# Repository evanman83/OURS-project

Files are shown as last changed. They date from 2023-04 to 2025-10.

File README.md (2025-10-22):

# OURS Project - DIY Open-Source Linux Smartphone

## MISSION:

I wanted to give people more options and control over their most personal device, so I created an **O**pen-source, **U**pgradable, **R**epairable **S**martphone, that is also completely free of Big Tech. It's not theirs, it's O.U.R.S. 

Below are the complete hardware and software instructions to build your own OURphone. Please enjoy, upgrade, tinker, improve and evolve my original design as you see fit, and share your upgrades here. Find me on [LinkedIn](https://www.linkedin.com/in/boyofthefuture/) if you have any questions / ideas.

**Version 1 was completed in 2024 - instructions are below. We are now busy with version 2**

**Join us on our [Telegram group](https://t.me/ourphonechat).**

**We are raising funds for version 2! Please support our campaign at [BuyMeACoffee](https://buymeacoffee.com/ourphone).**

## VERSION 1 PLANS

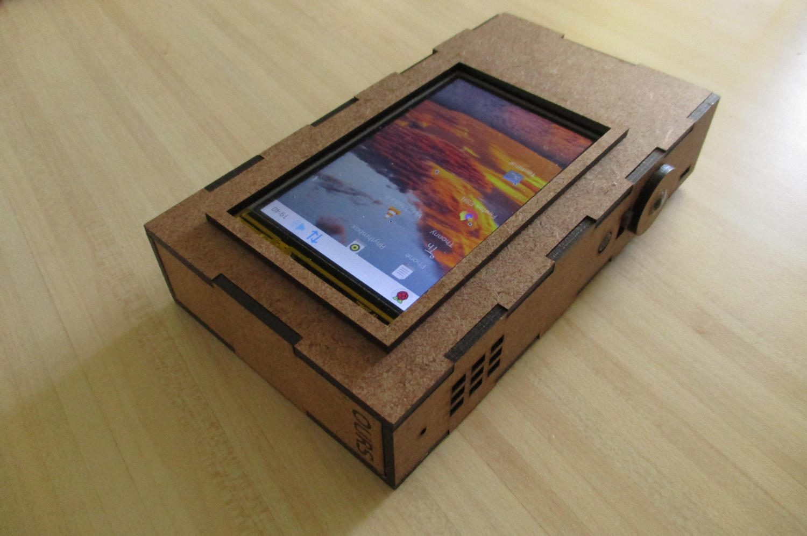
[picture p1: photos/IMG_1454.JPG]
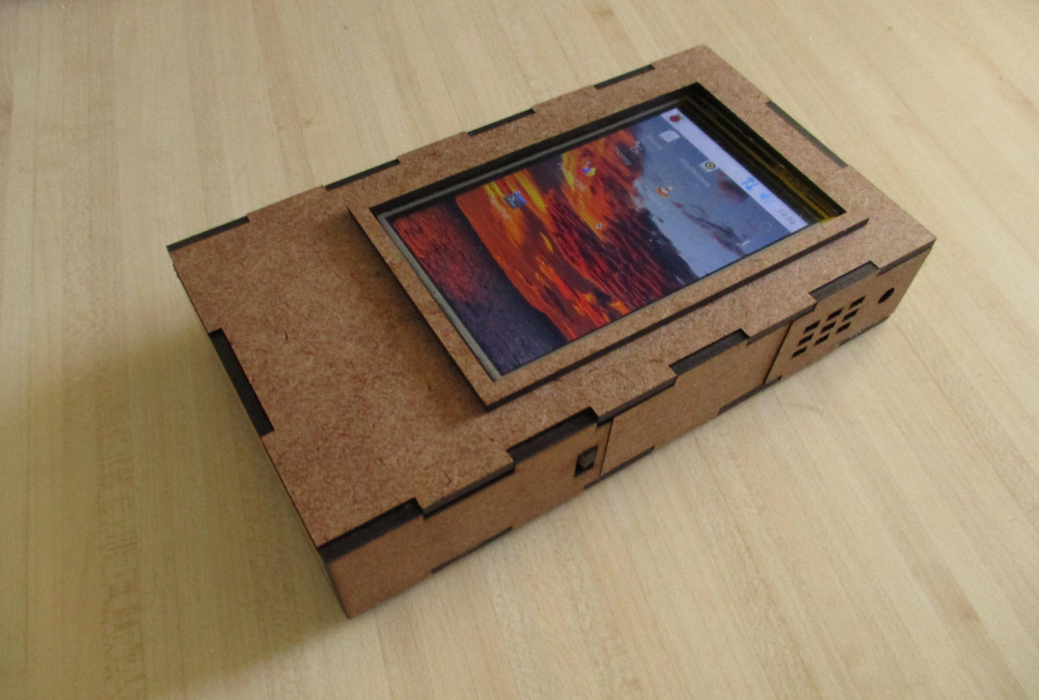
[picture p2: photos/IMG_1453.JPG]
 

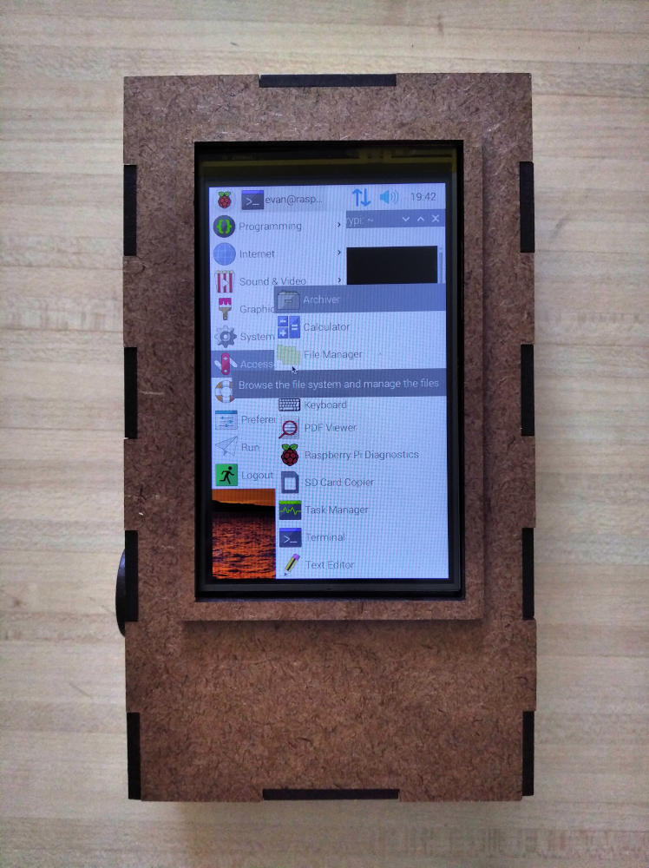
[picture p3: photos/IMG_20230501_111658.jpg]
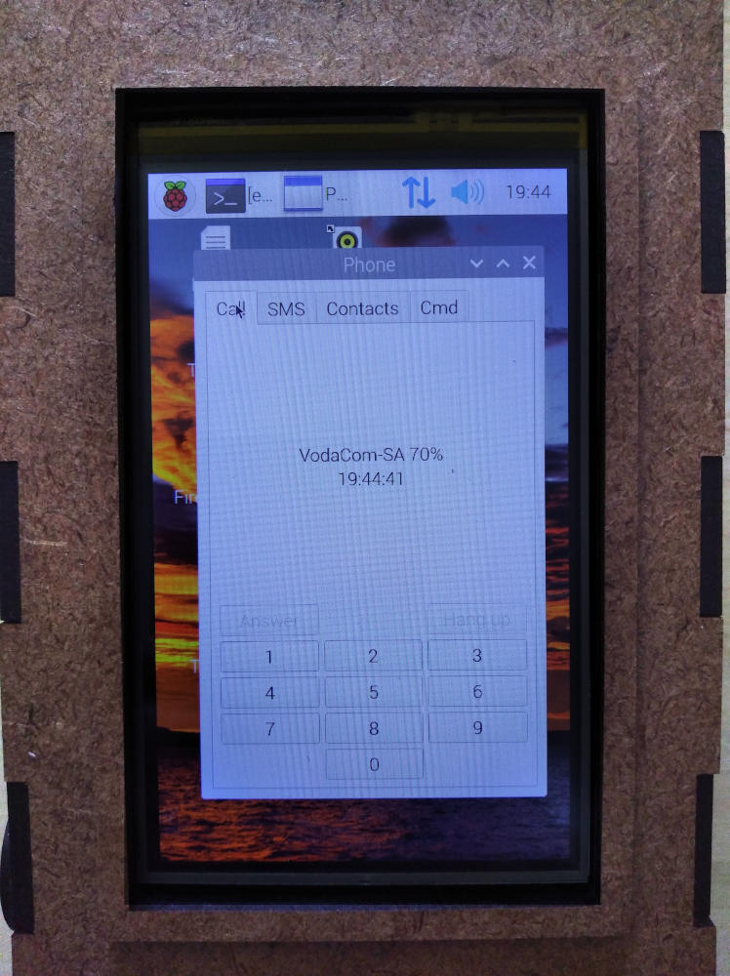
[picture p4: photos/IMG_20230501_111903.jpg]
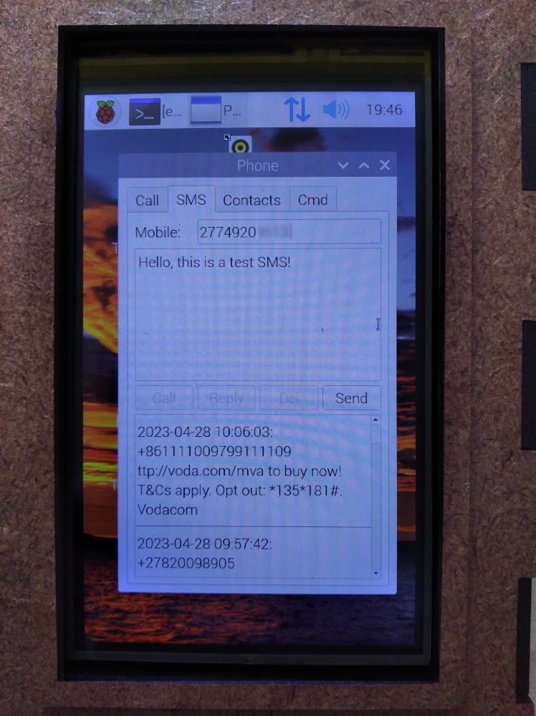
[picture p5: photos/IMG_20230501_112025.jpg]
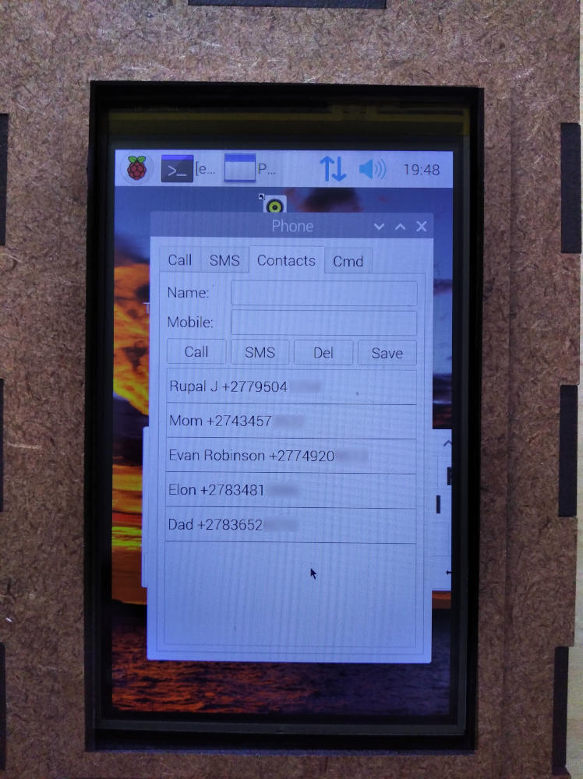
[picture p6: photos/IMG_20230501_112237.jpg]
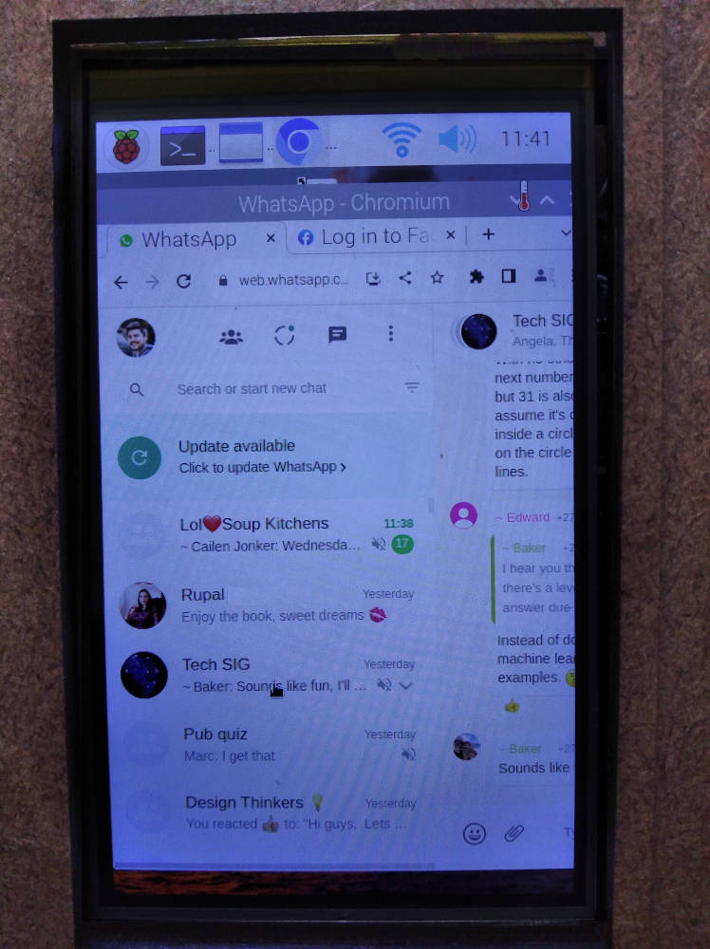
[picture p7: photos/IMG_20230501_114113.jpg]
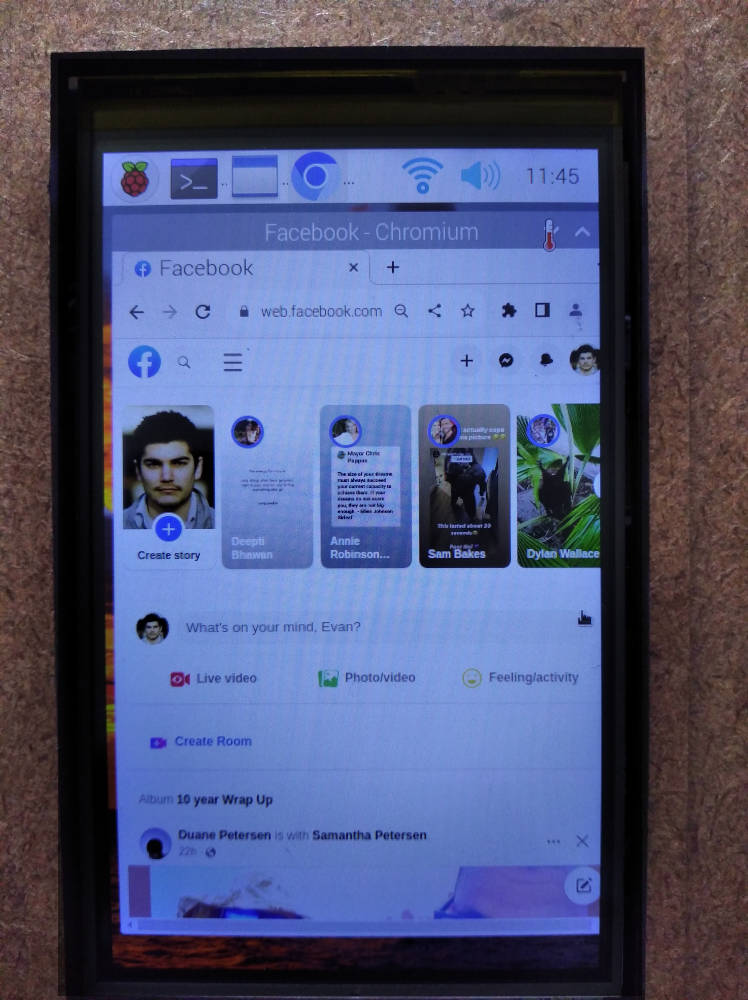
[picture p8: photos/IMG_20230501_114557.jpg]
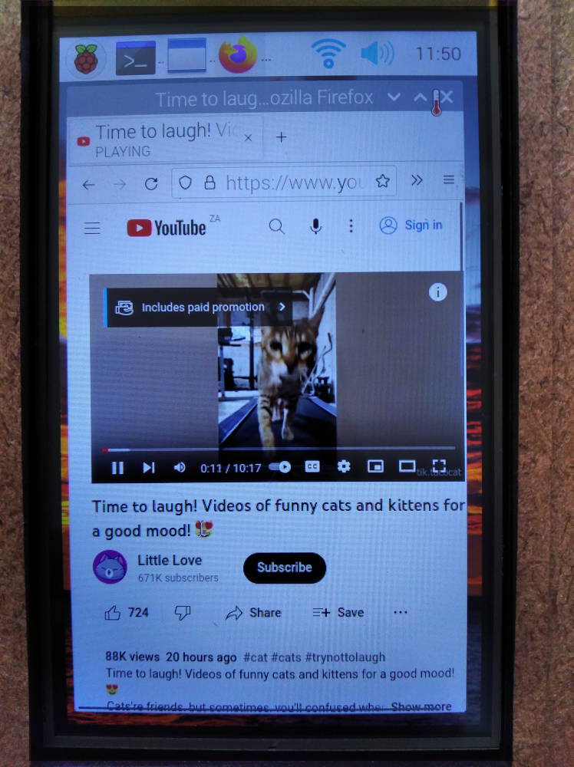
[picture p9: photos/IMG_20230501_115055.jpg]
      

## SPECS LIST

- 4G LTE internet
- Call, SMS, Contacts book (contains a SIM7600 with sim card)
- Quad Core 1.2GHz Broadcom BCM2837 64bit CPU
- 1 GB RAM
- Running Raspbian - a Debian Linux OS with installable app store
- Capable of running Facebook, WhatsApp, YouTube etc in browser
- 4 inch 480 x 800 colour touch screen
- 5MP colour camera
- GPS (in browser)
- Wifi
- Bluetooth audio
- 1 watt onboard audio speaker
- 3 USB ports
- "Convergent": HDMI port to plug in external monitor, USB to plug in keyboard and mouse
- Screen lock switch
- 9cm x 16cm x 3cm
- 5 hours battery life

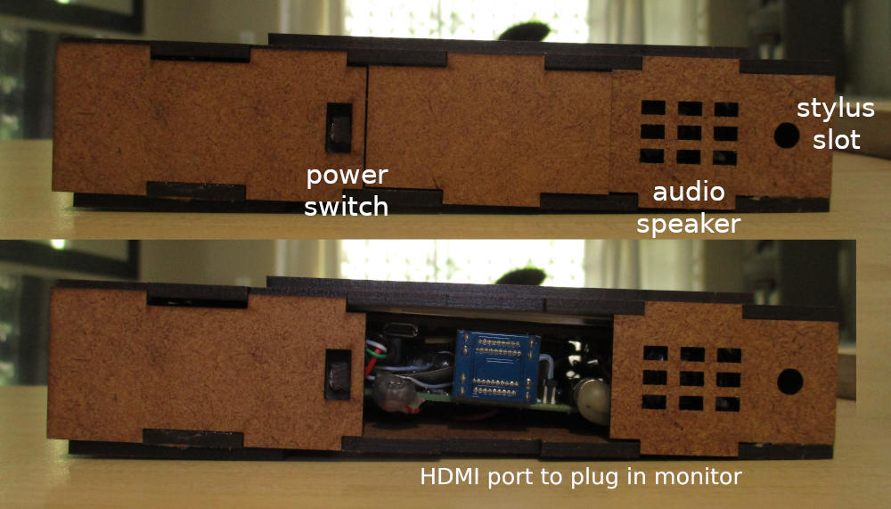
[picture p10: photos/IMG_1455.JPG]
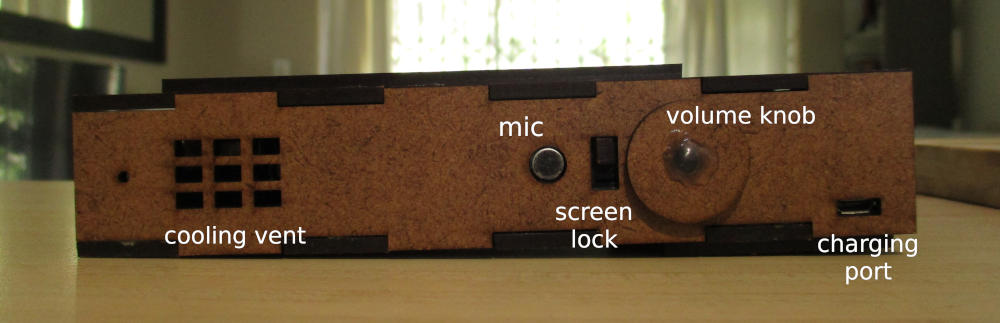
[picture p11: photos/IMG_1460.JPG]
 
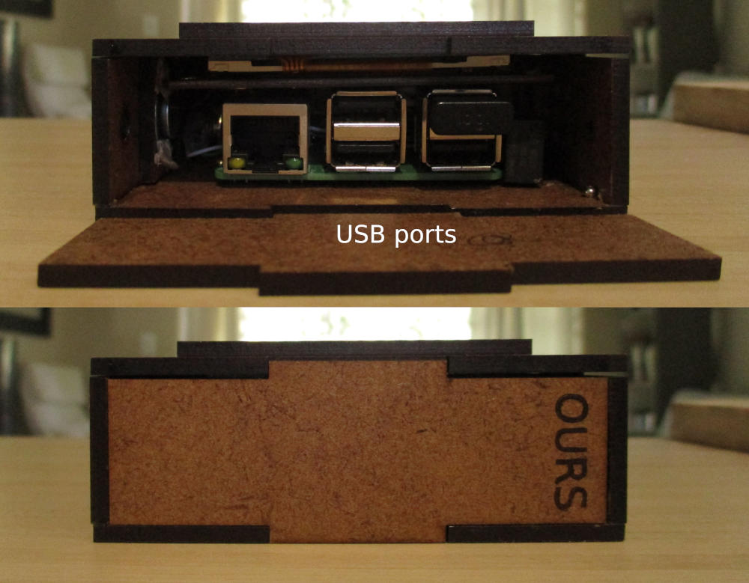
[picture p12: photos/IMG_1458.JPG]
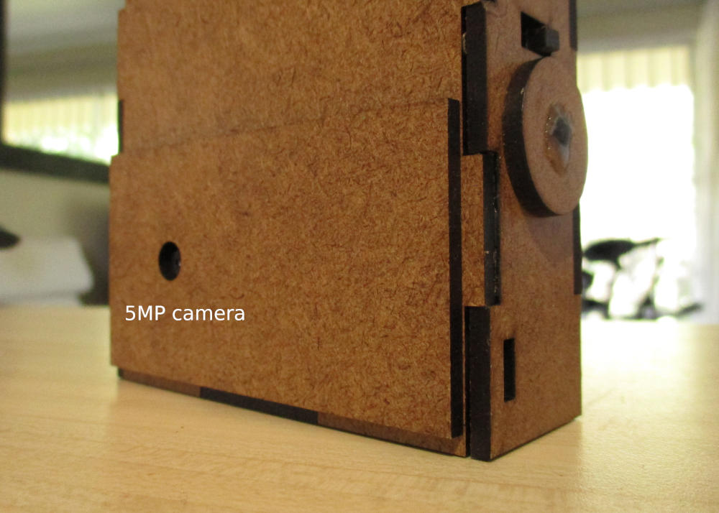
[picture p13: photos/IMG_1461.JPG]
 

## HOW IT WORKS
The Raspberry Pi provides the basic functions of a computer, now made portable by the two 3.6v batteries, down-converted to 5.1V DC. Telephony (calls and SMS) is made possibly via the Waveshare 4G HAT with a normal mobile network SIM card contained therein. The Pi communicates with the 4G HAT via ordinary AT commands. The startup.sh script runs the configuration necessary to activate a 4G mobile internet connection. The phone.py app provides a UI for dialling and calling, sending, receiving and replying to SMS, adding and removing records from a simple Address Book. The built-in microphone and speaker allow normal voice calls.

## GUIDING PRINCIPLES

- Low cost, off-the-shelf electronic components
- Less soldering / destroying, more connecting / assembling
- Share everything required to replicate
- Modular, standardised parts
- Browser-based PWAs are the future of installable apps

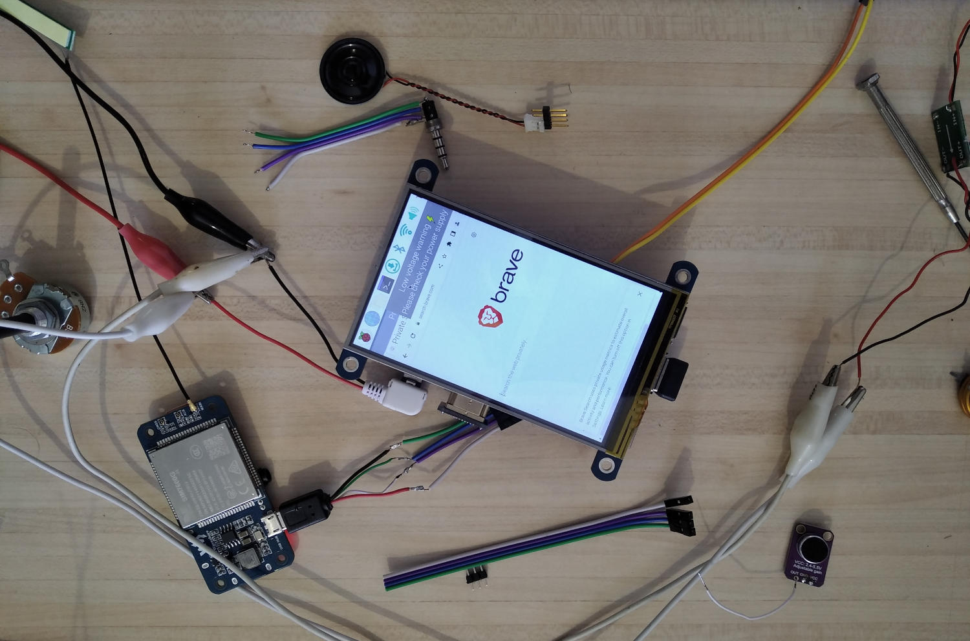
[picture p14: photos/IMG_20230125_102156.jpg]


## IMPROVEMENTS TO MAKE

- Use a faster Raspberry Pi with more RAM, or another SBC, or the super small RPi 4 Compute Module
- Use a capacitative touch screen, not resistive touch
- A bigger screen would be nice
- Eliminate audio whining / cracking (I think this is an RPi 3 problem, or audio amp needs isolation)
- Use shielded cables for audio carrying wires
- Add a microphone / USB audio card to enable audio on video recordings
- Connect phone call audio into Bluetooth (not just device audio)
- Audio jack
- Make less brick-like
- Customise Raspbian so the UI is more usable by finger (perhaps flash another OS)
- Detect and display remaining battery life
- Extend battery life, perhaps convert DC voltage UP instead of DOWN, or down-clock the RPi CPU temporarily

## HOW TO BUILD

Buy all the parts in *parts-list.xls*. Connect them based on *schematic.ppt*.

You can snap together a working version quite quickly with just the following (no soldering required):
- Raspberry Pi
- 4G HAT + GSM and GPS antennas
- Raspberry Pi power supply
- Waveshare touchscreen
- Raspberry Pi camera (optional)
- Headphones with built-in mic
- Some USB cables
- Operational mobile phone SIM card with airtime and data

Copy the files below into the Raspberry Pi home directory:
- startup.sh (auto-start script to turn on internet)
- phone.py (the app that allows calls, SMS, Contacts)
- location-provider.py (presents stored GPS coordinates at a URL for web-based location providers)
- ringtone.wav (your phone's ringtone - replace as you wish!)
- mobile-keyboard.xml (a custom keyboard based on the match keyboard software)

Follow the instructions listed in *setup_commands.txt* to ready the Raspberry Pi, setup internet, and get the phone.py app working.

### Making the cables smaller
There are many USB and audio plugs being used in the project. These are too big to allow packaging the phone's components into the wooden phone cover (box) designed for it. To make these smaller, I used thin wire to make new cables, with custom plugs on the ends. I made the plugs by using radically stripped down versions of the male plugs, taking off extra plastic housing, grinding off unnecessary bits and even bending some parts at right angles. Then I soldered on new leads and covered it with hot glue so that they are robust enough to force into tight spaces.

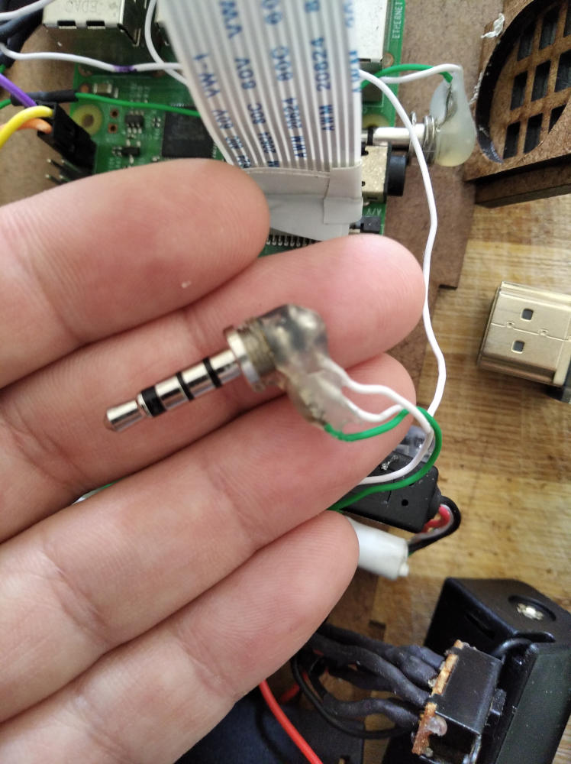
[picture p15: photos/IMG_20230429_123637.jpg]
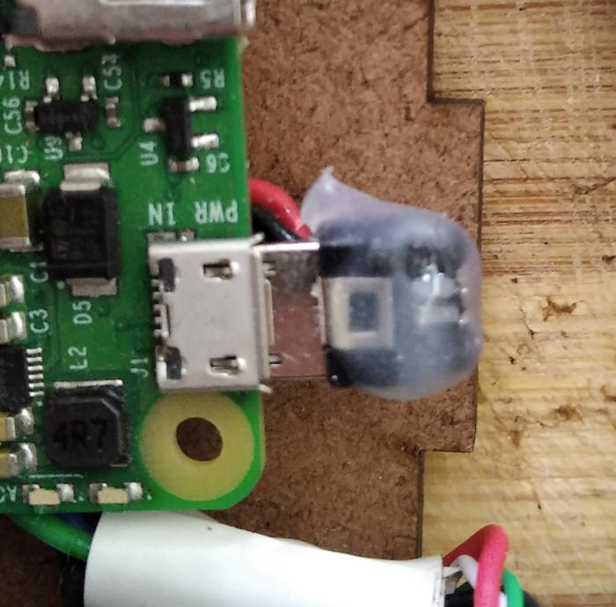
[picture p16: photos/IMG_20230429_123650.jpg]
 

To save even more space I soldered USB connections directly to the back side of the Raspberry Pi. This was the plug going to the 4G HAT.

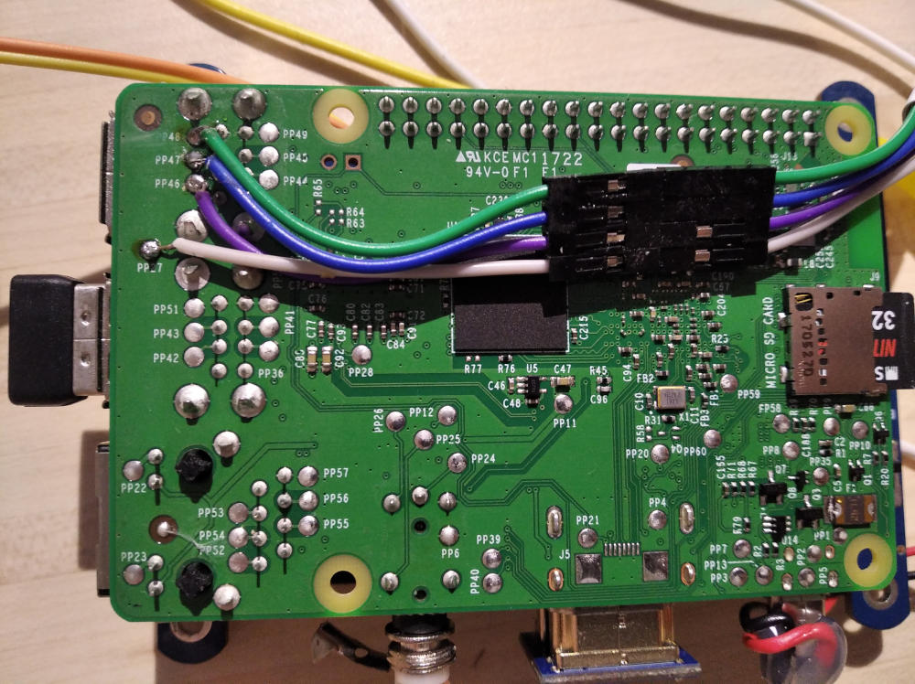
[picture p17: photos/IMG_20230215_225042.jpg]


### Making the Waveshare 4G HAT smaller
This is a challenge because the 4G HAT sits in between the touch screen and the Raspberry Pi itself. It is a tight, tight squeeze. I used a combination of a Dremel tool (small rotary grinder) and miniature steel cutters to painstakingly cut off the large USB ports and the two thick metal pins. These proved useless for carrying USB data, so I couldn't use them anyway - only the micro USB port seemed to work (despite many messages to their Customer Support). Be EXTREMELY careful removing these big items because it is very easy to cause massive physical destruction by lifting a track off the PCB, and then your module (the most expensive part of the build) is dead and unusable :( Only attempt if you have a surgeon's hand.

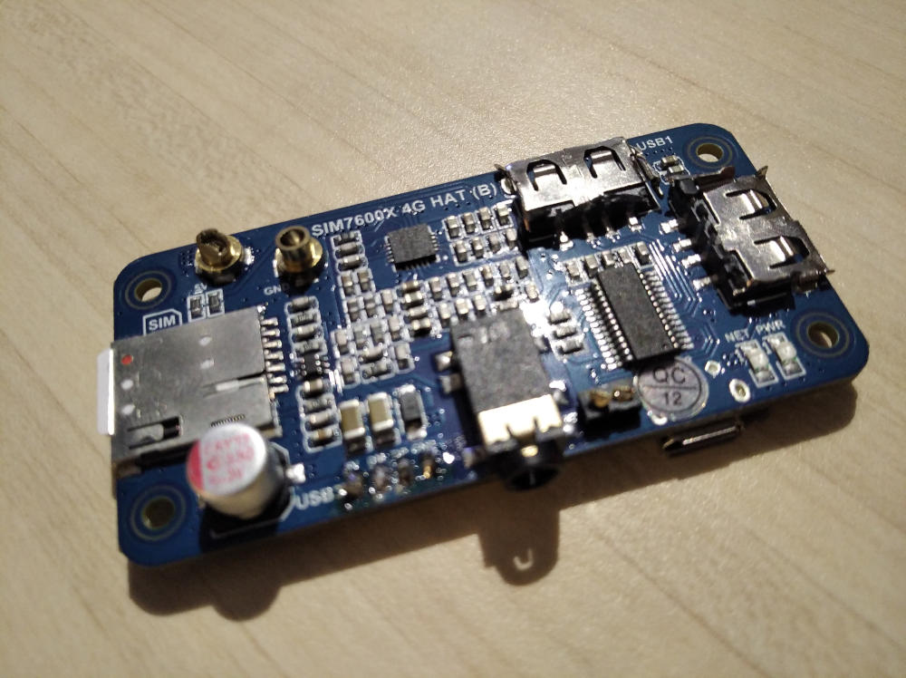
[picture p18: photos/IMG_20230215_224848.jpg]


Once these items are removed and the whole device is now slim, I hot glued the GSM and GPS antenna plugs and wires in place so they are not so fragile, and wrapped the whole thing in insulation tape.

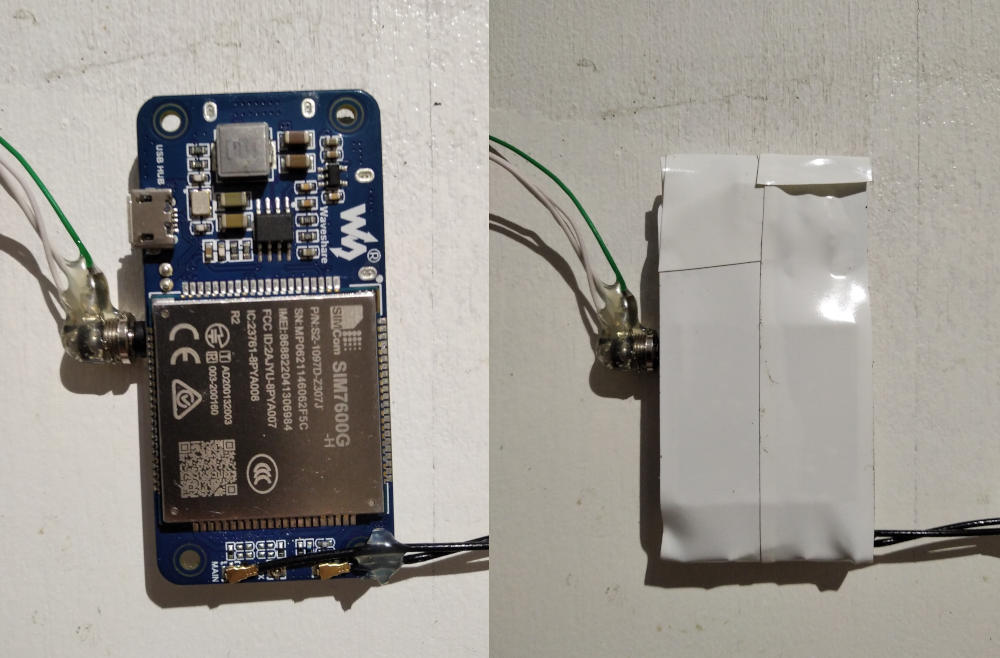
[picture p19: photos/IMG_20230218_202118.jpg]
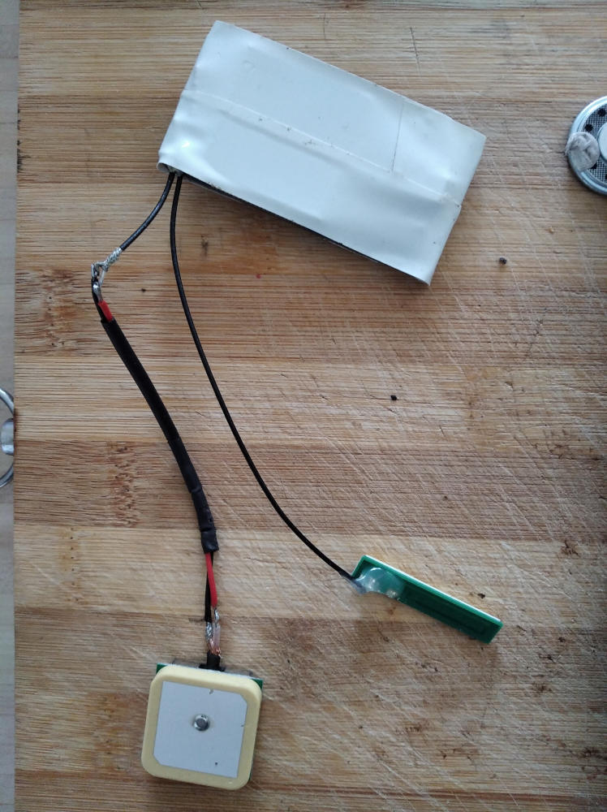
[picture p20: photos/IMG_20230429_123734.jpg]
  

The GSM antenna provided is too big. So I purchased a PCB GSM antenna and soldered that onto the cable instead. It works ok, but signal is never 100%, only good-ish.

The GPS antenna is also too big. So I crushed it slowly in a clamp and used a screwdriver to prise off the plastic casing. This revealed a much smaller GSM antenna chip, like a hard metal square. I soldered this onto the cable instead and replaced the whole plug system with just one little neat cable.

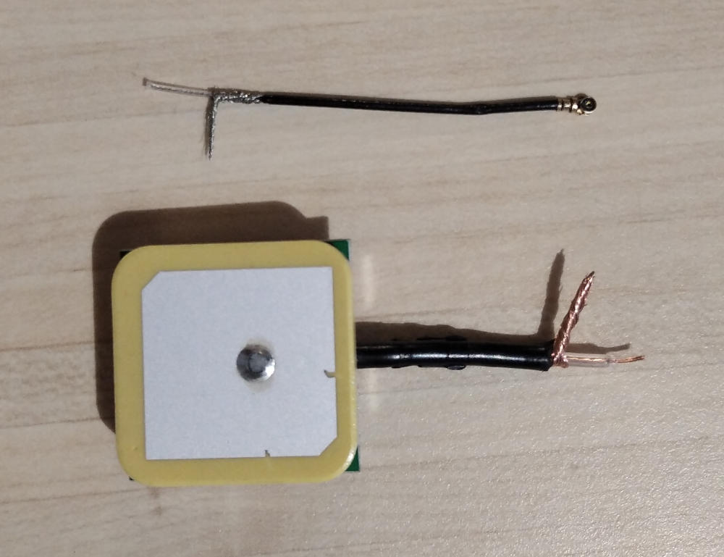
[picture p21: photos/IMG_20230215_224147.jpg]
 

### Laser cut the phone cover ###

Email the file *laser-cut-cover.dxf* to your nearest laser cutting facility. Use 3mm MDF board - that is what the design has been made to use. You won't be able to use a thinner board without modifying the design.

You can also 3D print all the parts, here's the link : https://www.thingiverse.com/thing:6063147

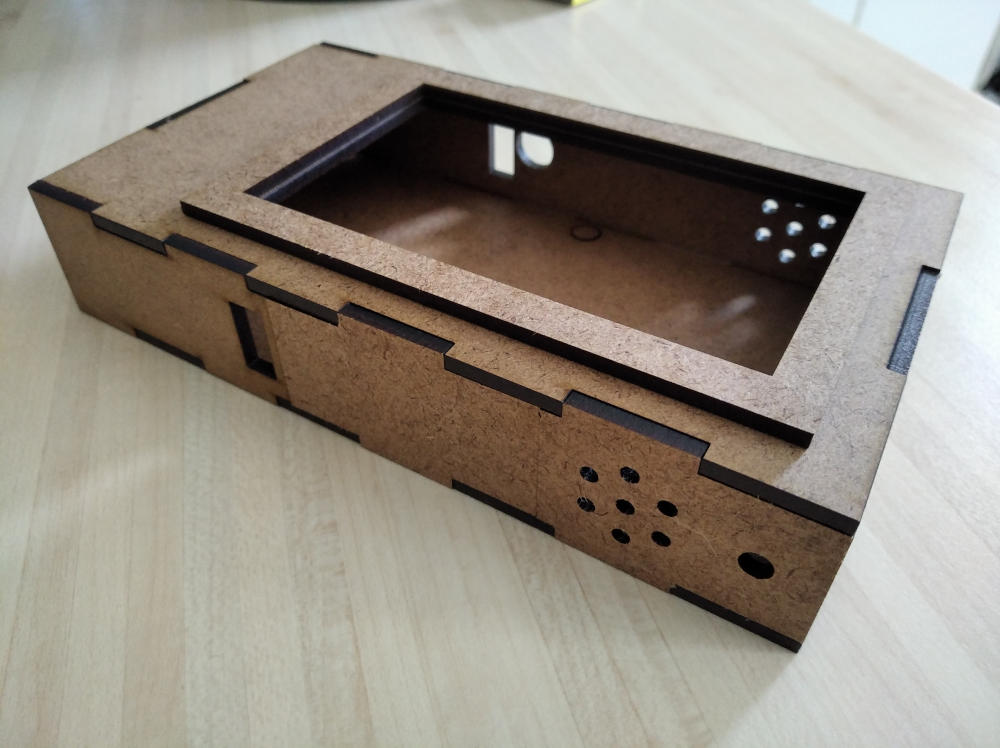
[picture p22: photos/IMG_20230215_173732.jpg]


### Assembly and construction
This is best described with pictures, but the main steps are:

1. Make new male plugs for the micro USB and male 3.5mm TRRS / stereo plugs (as described above).
2. Solder all the wires for the charger, power switch and power supply. Set the DC/DC converter to 5.1 VDC. Charge the batteries up for the first time, with the power switch in OFF / charging mode. Test whether the system can boot up and connect to the web - outbound calls and internet use a lot of current / make current spikes.
3. Solder in the audio amp, speaker and volume knob. Play a test mp3 (I downloaded the RhythymBox app) and see how loud it plays over the speaker.
4. Solder in the relay and screen lock switch. When the phone app is running, switching the screen lock switch should turn off the LCD screen and disable the touch controls. When a phone call begins, the relay should switch off the default Raspberry Pi audio and instead connect the phone call audio to the loudspeaker.
5. Connect all the batteries, wires and plugs and test: Internet, phone call, SMS, GPS, music playing. There is a lot of guidance for troubleshooting in the file setup_commands.txt (provided above).
6. Insert the 4G HAT between the touchscreen and Raspberry Pi, with audio and power cables pointing out the bottom right hand corner of the screen (facing the screen).
7. Fold the camera ribbon cable under the 4G HAT and over and under the batteries - stick the camera in place with Prestick putty. (this system was annoying because every time I needed to remove the electronics from the cover I had to unwrap the camera - rather implement some kind of snap plug for the ribbon cable to make this easier)
8. Stick the speaker with putty over the top right-hand grill (9 holes).
9. Place the GPS antenna next to the top left-hand grill (9 holes). GSM antenna can go down the left-hand side of the cover.
10. Start glueing the case together, starting from the bottom upwards, finishing with the front cover.

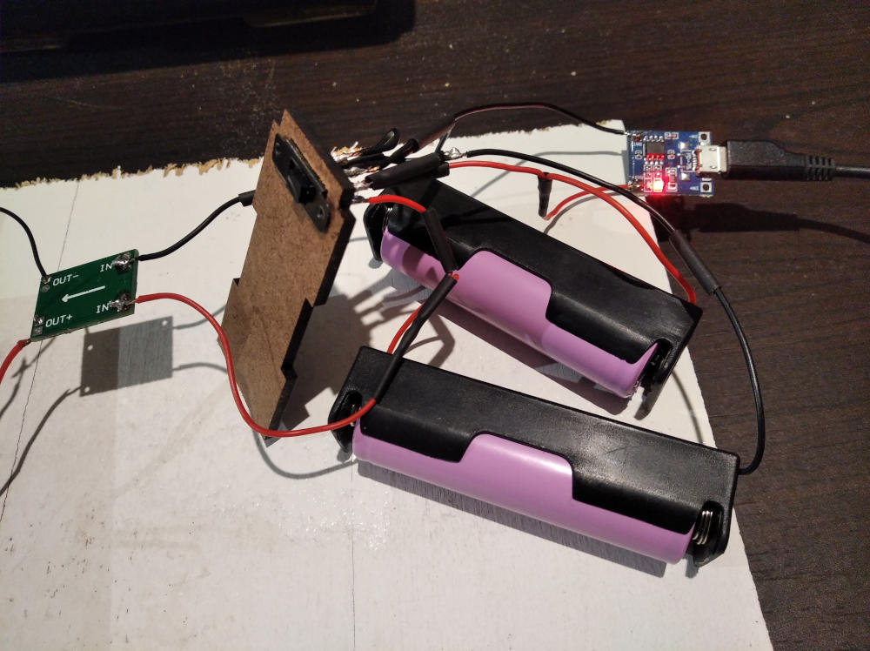
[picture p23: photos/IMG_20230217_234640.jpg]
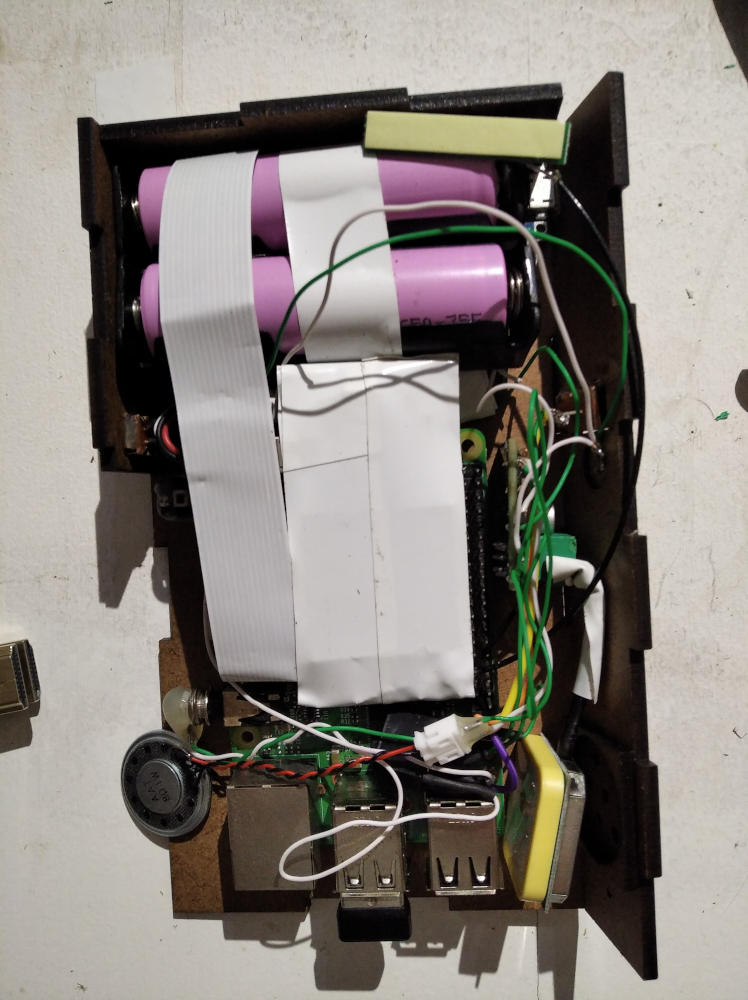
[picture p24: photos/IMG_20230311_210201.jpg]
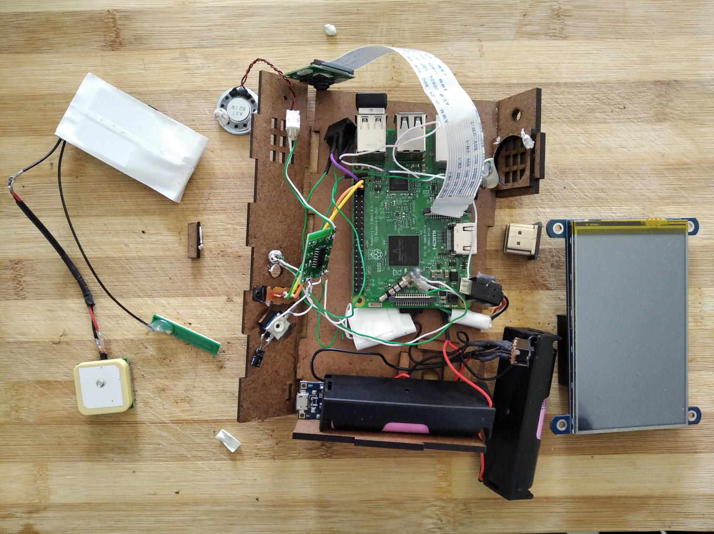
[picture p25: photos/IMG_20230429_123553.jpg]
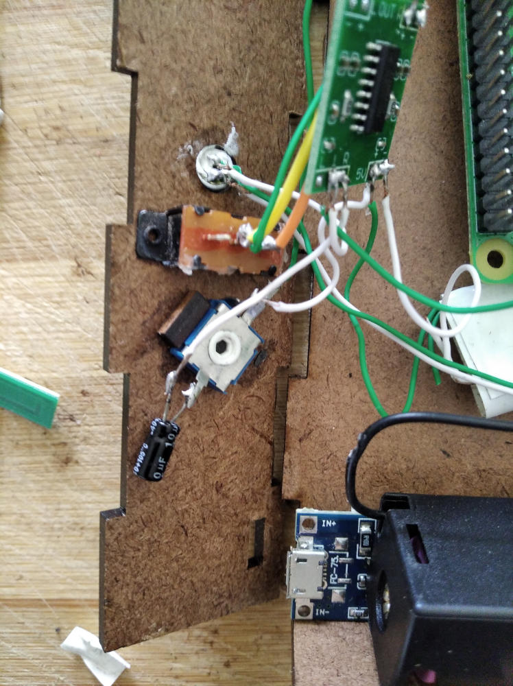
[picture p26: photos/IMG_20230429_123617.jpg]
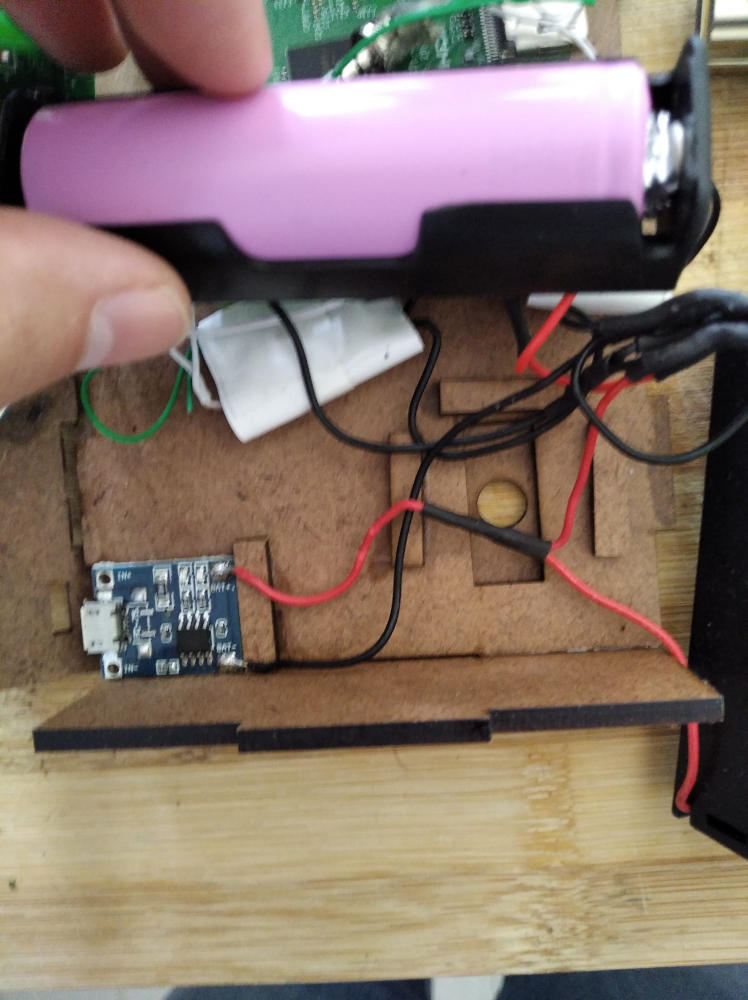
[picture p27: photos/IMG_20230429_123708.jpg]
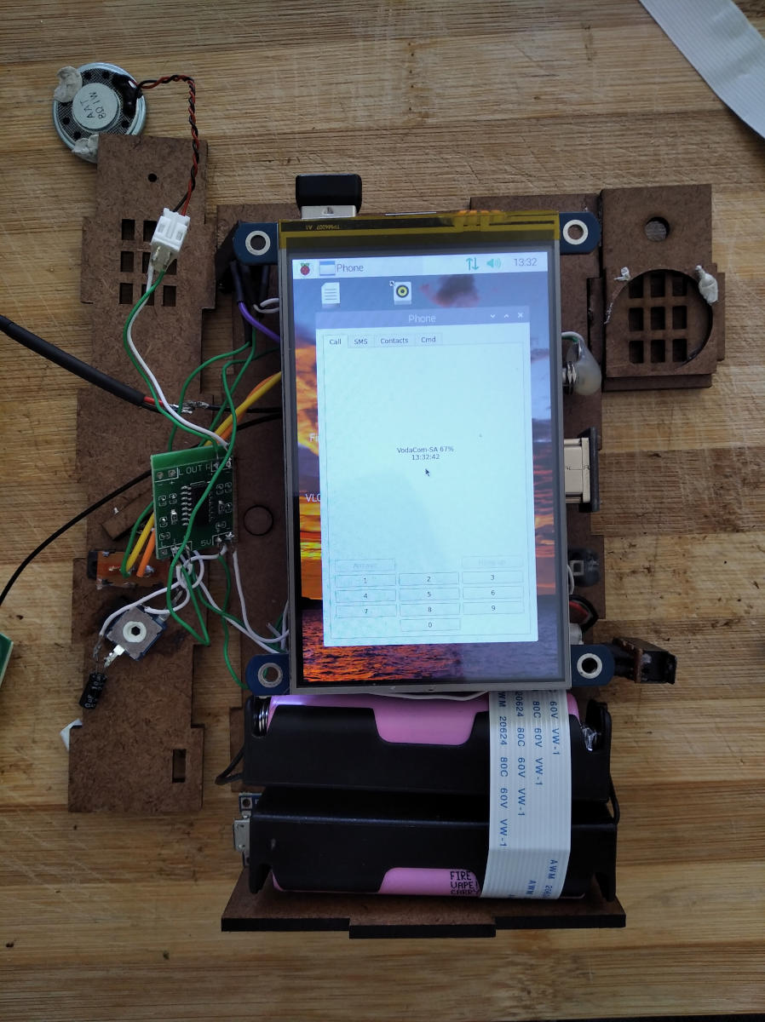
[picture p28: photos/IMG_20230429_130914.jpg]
     

See more construction photos in the /photos folder.

© Evan Robinson, 2023

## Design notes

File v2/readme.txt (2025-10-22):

OURphone v2

Goal:
- Faster CPU
- Thinner handset
- Longer battery life
- More usable
- More features
- More phone-like OS
- Better screen
- More attractive design
- More desireable

(better in every way)

Join the discussion on:
https://t.me/ourphonechat

Crowd-funding campaign: 
https://buymeacoffee.com/ourphone

Design principles:
A standardised compute module (CM4) will provide the computer and OS capability (incl bluetooth and wifi). 
This will dock with our custom PCB which will offer power management, a built-in SIM7600 chip for calls, SMS and 4G internet, a sound amp, headphone jack and USB camera.
We hope to stack all of this together between 12 - 15mm total height.

Update 8 Dec 2024:
Current Telegram group members: 103
Crowd-funding raised so far: $400
We have raised enough to hire a professional PCB designer on UpWork to design v1 of our new PCB. He is busy. 
We are working on the outstanding issues listed in our wiki document (find link in Telegram group).

Update 6 Apr 2025:
Current Telegram group members: 127
Crowd-funding raised so far: $1,100
After much debate we took the SIM7600 modem chip off the PCB board so that it becomes more modular and the PCB is cheaper to produce and iterate on. The SIM7600 will now plug in via an M2 connector.
I will start uploading the EasyEDA files into the V2 folder as they become available.
Next step is to order a PCB and test it.

Update 22 Oct 2025:
Current Telegram group members: 150
Crowd-funding raised so far: $1,910
After trying to order the PCB we discovered that a 3 layer PCB with filled vias cost an extra ~$300 to manufacture. This requirement was due to the power management chip we were using which was in a BGA form factor. We switched PCB designers, chose a different chip and simplified the design so that it now costs $66 to manufacture and assemble incl components.
The board has been manufactured and is being couriered now for testing.

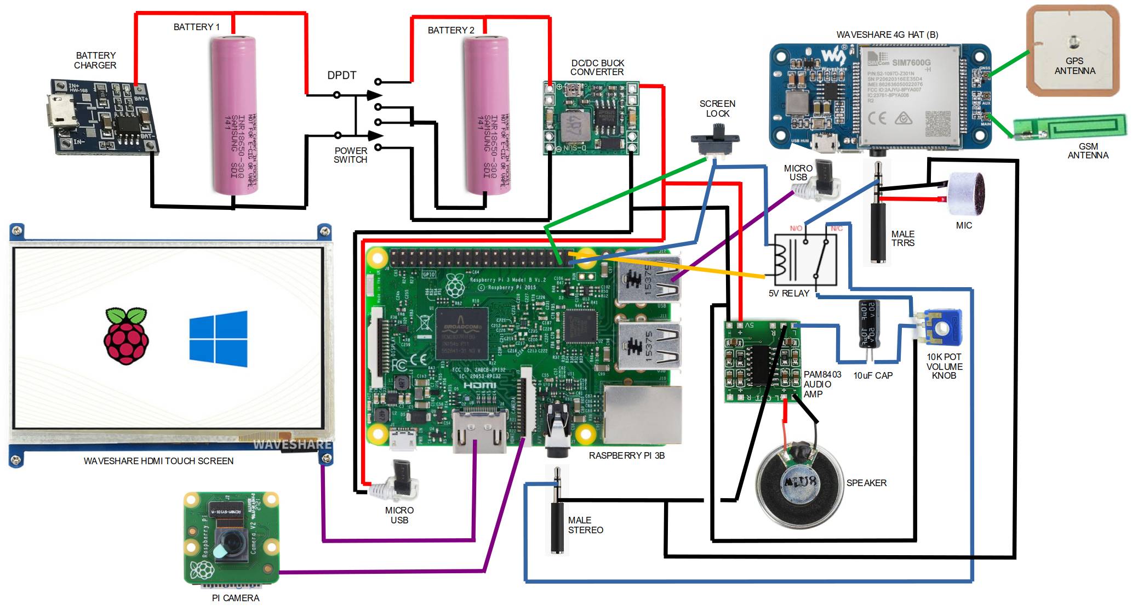
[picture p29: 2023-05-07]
schematic.jpg

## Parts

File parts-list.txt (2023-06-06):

Name									Price (ZAR)			
Waveshare SIM7600G-H 4G HAT (B) for Raspberry Pi			R 1,414	https://www.waveshare.com/sim7600g-h-4g-hat-b.htm			
Raspberry Pi 3 Model B							R 750			
Waveshare 4 inch 480x800 HDMI IPS LCD touch screen display HAT		R 630	https://www.waveshare.com/4inch-hdmi-lcd.htm		
Lithium-ion battery 3.7V 3500mAh 18650					R 189	https://www.mantech.co.za/ProductInfo.aspx?Item=310M0321		
Lithium-ion battery 3.7V 3500mAh 18650					R 189			
HKD Raspberry Pi camera mod 5MP						R 165	https://www.communica.co.za/products/hkd-raspberry-pi-camera-mod-5mp		
HKD DC/DC Buck Module 0.8-20V 2A converter				R 27	https://www.communica.co.za/products/bdd-dc-dc-buck-module-0-8-20v-2a		
Slide switch SPDT (screen lock switch)					R 10			
Slide switch DPDT (main power switch)					R 11			
Micro USB Lithium 18650 battery charger 1A (TP4056 chip)		R 15	https://www.mantech.co.za/ProductInfo.aspx?Item=15M5361-A		
HKD GSM antenna on IPEX 13 connector					R 19	https://www.communica.co.za/products/hkd-gsm-antenna-on-ipex-13-con		
Mini condensor microphone						R 27	https://www.communica.co.za/products/mic-e1-mini		
0.86inch 1W 8Ohm speaker						R 17	https://www.communica.co.za/products/spkr-0-86in-1w-8ohm-22x3mm		
HKD PAM8403 audio amplifier						R 20	https://www.communica.co.za/products/hkd-pam8403-aud-amp		
Miniature 5V relay							R 16			
10uF electrolytic capacitor						R 1			
10K potentiometer							R 4			
3.5mm audio plug 4 pole (male TRRS)					R 25			
3.5mm audio plug 3 pole (male stereo)					R 25			
Micro USB 5P plug in white housing R/A – rewireable			R 34	https://www.mantech.co.za/ProductInfo.aspx?Item=15M9739		
Micro USB 5P plug in white housing R/A – rewireable			R 34			
Battery holder for 18650						R 8	https://www.mantech.co.za/ProductInfo.aspx?Item=72M6006		
Battery holder for 18650						R 8			
				
Total:									R 3,639	
									198 USD	
									180 EUR	
									(27 April 2023 rates)

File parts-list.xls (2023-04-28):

Name | Price (ZAR)
Waveshare SIM7600G-H 4G HAT (B) for Raspberry Pi | R 1414
Raspberry Pi 3 Model B | R 750
Waveshare 4 inch 480x800 HDMI IPS LCD touch screen display HAT | R 630
Lithium-ion battery 3.7V 3500mAh 18650 | R 189
Lithium-ion battery 3.7V 3500mAh 18650 | R 189
HKD Raspberry Pi camera mod 5MP | R 165.002
HKD DC/DC Buck Module 0.8-20V 2A converter | R 27.002
Slide switch SPDT (screen lock switch) | R 9.775
Slide switch DPDT (main power switch) | R 11.0975
Micro USB Lithium 18650 battery charger 1A | R 15
HKD GSM antenna on IPEX 13 connector | R 18.998
Mini condensor microphone | R 27.3125
0.86inch 1W 8Ohm speaker | R 17.25
HKD PAM8403 audio amplifier | R 20
Miniature 5V relay | R 16.4105
10uF electrolytic capacitor | R 1
10K potentiometer | R 4
3.5mm audio plug 4 pole (male TRRS) | R 25
3.5mm audio plug 3 pole (male stereo) | R 25
Micro USB 5P plug in white housing R/A – rewireable | R 34
Micro USB 5P plug in white housing R/A – rewireable | R 34
Battery holder for 18650 | R 7.8775
Battery holder for 18650 | R 7.8775
 | R 3638.6025 | 198 USD | 180 EUR | (27 April 2023 rates)

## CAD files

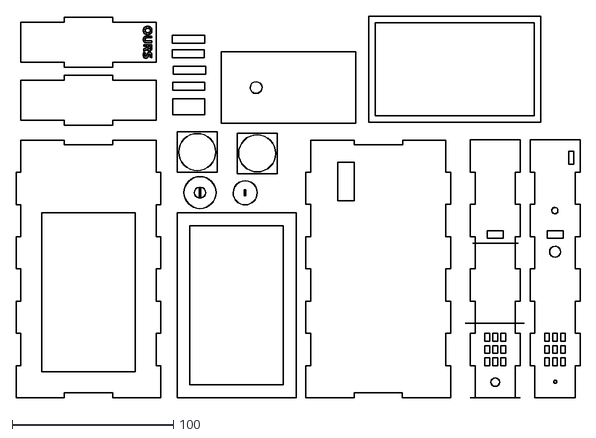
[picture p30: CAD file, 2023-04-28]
laser-cut-cover.dxf
350.0 x 236.8

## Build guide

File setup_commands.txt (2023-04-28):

#################### LINUX SETUP COMMANDS ############################

# use Raspberry Pi Imager application to flash Raspberry Pi OS (32 bit)
# put newly flashed SD card into Raspberry Pi and turn on
# I did the install process with the touchscreen shield plugged in + a USB mouse + keyboard
# during setup, connect to wifi and allow the software update to proceed
# if the screen goes off during install, move the mouse (or it's rebooting)
# do all of the below cammands on the Raspberry Pi, in terminal

# see what OS is running - mine said "Raspian GNU/Linux 11 (bullseye)"
cat /etc/os-release command

# see what processor and model is running - my model was "Raspberry Pi 3 Model B Rev 1.2"
cat /proc/cpuinfo

# --------- get touchscreen working -----------------

# This process was very roundabout. The documentation on the Waveshare page (https://www.waveshare.com/wiki/4inch_HDMI_LCD_(H)) was incorrect when I visited it. The touchscreen worked immediately out of the box, however the touch part didn't work. I followed the steps below:

# clone the repo from Waveshare
git clone https://github.com/waveshare/LCD-show.git

# go into the newly created folder
cd LCD-show

# install the package relevant for your touchscreen model, mine was the 800x480 model
sudo ./LCD4-800x480-show

# the Pi should install then reboot, now in landscape mode

# open up the boot/config.txt file
sudo nano /boot/config.txt

# scoll down and make sure the below is present
hdmi_group=2
hdmi_mode=1
hdmi_mode=87

# insert this special line under the above - I don't know what this does
hdmi_cvt=800 480 60 6 0 0 0

# change 'swapxy' to 1 in the below line to get the portrait mode working for the stylus
dtoverlay=ads7846,cs=1,penirq=25,penirq_pull=2,speed=50000,keep_vref_on=0,swapxy=1,pmax=255,xohms=150,xmin=200,xmax=3900,ymin=200,ymax=3900

# comment out the below
#display_rotate=3
#hdmi_drive=1
#hdmi_force_hotplug=1
#max_usb_current=1

# then exit and save

#reboot the system to apply new settings
sudo reboot

# the screen should be portrait mode again
# if you use the stylus you should see the touch screen responds to it now, but needs calibrating

# under the main Pi menu, under Preferences, click on Calibrate Touchscreen
# now touch the stylus on the four points, step by step
# the screen will then show instructions, something about copying the config below into /etc/X11/xorg.conf.d/99-calibration.conf
# right click then copy the config to clipboard
# Ctrl+C to exit
sudo nano /etc/X11/xorg.conf.d/99-calibration.conf

# then paste in the copied calibration, exit and save
# the stylus showuld now work perfectly!

# --------- get internet working -----------------

# make sure your SIM card in the HAT actually has airtime and data before you plug it in
# I used these instructions as a guide: https://www.waveshare.com/wiki/Raspberry_Pi_networked_via_NDIS
# but my full list of commands is below:

# run the below command to list USB devices
watch -n 1 lsusb -t

# plug in your Waveshare 4G HAT via USB, make sure the GSM antenna is plugged in
# after 5 seconds you should see one of the ports suddenly get a whole bunch of other sub-ports
# the red light on the Waveshare 4G HAT should be on
# a second red light should start blinking after about 15 seconds - this means it has established a web connection
Ctrl+C to exit the viewing of USB ports

# install the Minicom diagnostic tool - your new friend
sudo apt-get install minicom

# open up Minicom
# NOTE: It is my assumption that your device will also be at /dev/ttyUSB2 - it may not be! 
# if it's not there, you must edit the config at the top of phone.py, and use a different address below.
sudo minicom -D /dev/ttyUSB2

# type in your first AT command:
AT
# you should see "OK"
# type in:
ATE
# you should see "OK", now everything you type will be echoed on the terminal so you can see it
AT+COPS?
# you should see your SIM card's mobile network name
AT+CSQ
# you should see "CSQ: x,y" where x is your current signal strength out of 30
AT+CNMP=38
# turns on LTE/4G as default web connection, not 2G
ATD+your mobile phone number in international format, followed by semicolon e.g. ATD+27734567890;
# should call your phone :)
AT+CHUP
# should hang up the call
# well done! now your phone module is working! Let's get the internet working
AT+CUSBPIDSWITCH=9001,1,1
# should reply "OK"

Ctrl+A, then X, then Yes to exit Minicom.

# download the driver file from Waveshare
wget https://www.waveshare.com/w/upload/0/00/SIM7600_NDIS.7z
# install the 7 zip archiving software
sudo apt-get install p7zip-full -y
# now unzip the downloaded file to a new folder
7z x SIM7600_NDIS.7z   -r -o./SIM7600_NDIS
# open up the new folder
cd SIM7600_NDIS
# look at the contents
ls
# there should be 8 files there

# install the kernel headers for Raspberry Pi
sudo apt install raspberrypi-kernel-headers

# compile the driver:
# get sudo priviledges
sudo su
# make and clean up the directory
make clean
# make
make
# list items in the folder
ls

# remove the default Raspberry Pi qmi_wwan driver module
rmmod qmi_wwan

# install the driver
insmod simcom_wwan.ko
# list the operational driver modules, and see if "simcom_wwan" is listed in there?
# it should be there, and qmi_wwan must not be there
lsmod

# open the wwan0 interface - should reply "wan0 up"
sudo ifconfig wwan0 up

# now go into Minicom and type the below AT command
sudo minicom -D /dev/ttyUSB
AT$QCRMCALL=1,1
# exit Minicom

# install the udhcpc client
apt-get install udhcpc

# open the connection and get an IP address
udhcpc -i wwan0

# now if you run the below, you should see the "wwan0" connection has "inet 100.119.160.62" or some other IP address assigned to it
ifconfig -a

# do a ping of a public URL
ping -c3 www.linux.org

# now the problem is that the default qmi_wwan module pops up again after reboot, and simcom_wwan is forgotten,
# and those steps are annoying, so you need to create a startup file that runs the above commands right after reboot:
# in your home directory, make a new file
nano startup.sh
# paste in the contents of startup.sh

# then save and exit
# make the new file executable
chmod +x startup.sh

# now if you run the file with the below command it removes the old driver, installs the new, and turns on the web
# it might error out of qmi_wwan has already been removed and/or simcom_wwan has already been added - that's ok
sudo ./startup.sh

# to make this run automatically on startup, open up the cron editor
sudo crontab -e
# add this line at the bottom, change to your relevant directories, and note the log file for debugging (useful)
# remember to replace "evan" with your Pi's username, in this command, and those later on below
@reboot /home/evan/startup.sh >> /home/evan/startup-log.txt 2>&1
# save and exit
sudo reboot
# internet should work, with wifi off, straight after startup, automatically!

# Debugging the internet connection:
# There are a lot of pieces to the puzzle that are required to make the web connection work. These will help you:
# 1. Make sure there is sufficient power, if not, the Waveshare 4G HAT will keep on rebooting. If you see a yellow lightning bolt in the top right hand corner of your screen then you have insufficient power.
# 2. Make sure the NET LED is flashing red on the Waveshare 4G HAT card.
# 3. Check that the power is sustained and the USB connection is good but running "watch -n 1 lsusb -t" to watch the USB connected devices. The Waveshare 4G HAT device should be stable and not pop in and out.
# 4. Check to see that the default wwan0 driver "qmi_wwan" is NOT there but "simcom_wwan" IS THERE, by running "lsmod".
# 5. Check that the Waveshare 4G HAT is still operational by using Minicom and running some test AT commands.
# 6. Run "ifconfig -a" to see if "wwan0" exists and whether it contains an IP address after "inet" - this means it has a web connection.
# 7. If you are still stuck, try Waveshare's customer support. They responded usefully within 48 hours to several of my queries.
# 8. Have a look at startup-log.txt which the startup script writes to at each boot time.
# 9. Maybe extend the sleep times between steps in startup.sh.

# --------- get camera working -----------------

# edit the /boot/config.txt file and add in the line "camera_auto_detect=1" (exclude quotes)
sudo nano /boot/config.txt
# save and exit
sudo reboot
# on startup you should see the red LED on camera pulse briefly
# take a test photo!
libcamera-still -o test-image.jpg --qt-preview
# once you get the phone app working you can take photos from there without using the cmd

# --------- on screen touch keyboard working -----------------
# install matchbox keyboard
sudo apt-get install matchbox-keyboard
# now you should see the keyboard under 'Accessories'
# to make the keyboard more like a mobile phone keyboard, copy the 'mobile-keyboard.xml' into your home
# directory /.matchbox/keyboard.xml

# --------- get phone app working -----------------

# if we want to be able to use the Pi's GPIO pins (for example as a switch to turn on/off the screen)
# install the PIGPIO library
sudo apt-get install pigpio
# make the PIGPIO daemon start automatically on boot
sudo systemctl enable pigpiod
# install the PyQT5 database library - the phone app is written in PyQT5
sudo apt-get install python3-pyqt5.qtsql

# check if you can run the phone app from the cmd
python3 phone.py
# a GUI app showing the time should appear - this is the phone app
# if the Waveshare 4G HAT is connected, the display should show your network name and signal strength after a few sec
# if it doesn't work, maybe you need to install PyQt5 with "pip install PyQt5"

# make sure the phone app runs automatically on boot
# followed this: https://medium.com/@arslion/starting-python-gui-program-on-raspberry-pi-startup-56fb4e451cc1
mkdir .config/autostart
sudo nano autostart/MyApp.desktop
# typed in the below
[Desktop Entry]
Name=Your Application Name
Type=Application
Comment=Some Comments about your program
Exec=sudo /usr/bin/python3 /home/evan/phone.py
# then save and exit
# then make it executable
sudo chmod +x .config/autostart/MyApp.desktop
# after reboot the phone app should appear automatically on screen

# make sure GPS works in Firefox
# install Firefox
sudo apt-get install firefox-esr
# run the location-provider.py script manually for now
python3 location-provider.py
# you should see a URL, something like http://127.0.0.1:5000
# open up Minicom
sudo minicom -D /dev/ttyUSB2
# turn on GPS
AT+CGPS=1
# wait a minute or so, go outside, and make sure the GPS antennae is connected
AT+CGPSINFO
# this should output a location string to the console
# the phone.py app automatically fetches this string, and puts it into location.txt
# this txt file is served at the live URL by location-provider.py, outputting a json string that the browser can use
# open Firefox, type "about:config" as the URL
# replace geo.provider.network.url with the URL above e.g. http://127.0.0.1:5000
# if you open up http://127.0.0.1:5000 in the browser as a test (after successfully running phone.py with GPS on) you will see a json string of coords
# now make the script run on boot
sudo nano /etc/rc.local
# add in the below line
sudo python3 /home/evan/location-provider.py &
# save and exit

sudo reboot

# to switch off the screen aka "lock phone", attach two jumper cables to GPIO pin 26 and ground
# when you want to lock the phone, short these two with a switch
# the phone.py app detects this and runs the two shell commands below to turn off screen and disable touchscreen:
# xset dpms force off
# xinput disable 6

# you are done. you just built a damn smartphone.

#################################################################

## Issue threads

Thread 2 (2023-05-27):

Parts list

jodi319, 2023-05-27:
Your parts list does not have technical descriptions; for examples the "battery charger for 18650 batteries". Is this the IP2312 ?

Arcktosh, 2023-05-27:
Able to add a camera and some sensors?

evanman83, 2023-05-29:
@jodi319 - the exact charger used doesn't matter, just as long as it can provide 1 amp at least. I am no expert on battery charging so it's worth experimenting. I will update the parts list to mention that it uses the TP4056 chip. My exact part was this one: https://mantech.co.za/ProductInfo.aspx?Item=15M7777.

@Arcktosh - it has GPS and a camera on it, but sure, it can definitely do with more sensors!

Closed 2023-06-24.

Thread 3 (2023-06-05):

DXF files for 3D printing

Oceanique, 2023-06-05:
Hello,

I was wondering if you could upload the files you've created in STL ? That's because there's a lot more people who own a 3D printer than a laser cutting machine and I'm one of them ^^.

Thank you

evanman83, 2023-06-05:
I didn't design it for 3D printing, but I'm glad you did :) The maximum dimensions for the case (when assembled) are 9cm x 16cm x 3cm, so the main top and bottom pieces should be 90mm x 160mm and all the heights 3mm.

evanman83, 2023-06-05:
Please consider adding the link to your Thingiverse file into the Readme file under the "Laser cut the phone cover" section, so that everyone can benefit.

evanman83, 2023-06-24:
Yes those parts are meant to be separable, so that you can pop out the middle panel and access the HDMI port and plug in your monitor instead of the built-in screen if you want. Not NB.

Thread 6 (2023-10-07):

[SUGGESTION] Is it possible to use a phone-friendly Desktop Environment

anasouardini, 2023-10-07:
I've been tinkering with DEs in the past week and came across GNOME Phosh. While GNOME is already made to work with touchscreens, Phosh offers a premium experience.

As you might already know, the only tricky thing is going to be hardware support — I have not tested it on a rasp berry pi before.

Just throwing it out there; I hope I can use this project idea as a daily driver in the future.

evanman83, 2023-10-09:
Hi there, thanks for your suggestion. We have been discussing various OSs in our Telegram group and Phosh came up as one of the strong candidate options. Our next version is using an OrangePi CM4 board with stronger specs that can run Ubuntu, so Phosh should be easy to get going. We are busy waiting for our dev boards to arrive in the mail before we can continue...

anasouardini, 2023-10-09:
Thanks for the consideration.
Oh, Orange Pi! I can't wait.

Closed 2023-10-09.

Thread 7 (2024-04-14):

[Question] how different the process might be if I replicate this with an Orange pi 0?

anasouardini, 2024-04-14:
I'm thinking about using this for smaller phone for convenience.

evanman83, 2024-04-15:
Yes, great idea. We have been discussing which board to use for version 2, to make the phone smaller, faster and more power efficient. We had many discussions on our Telegram group (come join us - see link on main page). We decided on the OrangePi CM4 unit for now, so the problems we are solving regarding the graphics drivers and OS will be relevant to you if you want to use the Zero. We also have a link to a spreadsheet in the Telegram group description which shows all the boards we discussed.

NellowTCS, 2024-11-29:
I was just about to suggest using a cm4 or cm5! Maybe you could use the Raspberry Pi CM4/5 with Konsta's amazing Android port? (https://konstakang.com/devices/rpi4/ and https://konstakang.com/devices/rpi5/)

evanman83, 2025-01-07:
The raspberry Pi uses too much power to ever be a portable device with significant battery life, hence we chose the OrangePi CM4 because it has a functional sleep mode.

NellowTCS, 2025-01-07:
Good point!

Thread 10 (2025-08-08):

Similar concept by solo developer

DansDesigns, 2025-08-08:
Hey,

A couple of friends and I came up with the same idea during a conversation a few months ago, since then we have an almost complete PCB design , 3 different 3d printed case designs and working prototype using the Waveshare 6.25" HDMI touchscreen..

We have a rough working beta of a promotional teaser video (by incorporating the 3d files from easyeda and our case designs into Godot game engine) that is still being polished but if you would like to know more, please check out our website: https://alternitech.square.site/product/osm-phone/CNHHQKEK2Z5H344A6434YWD3

we also have a forum here: https://alternitech.freeforums.net/

We are continuing to work on our designs but we are very interested in pooling our resources if you have the same inclination?

Closed 2025-09-08.

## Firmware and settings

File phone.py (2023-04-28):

# config variables
screen_lock_rpi_pin = 26
audio_changeover_rpi_pin = 21
testing = False
serial_port = '/dev/ttyUSB2'

if (testing):
    # if running on your PC, these imports might be what you need
    from PySide2.QtWidgets import QMainWindow,QWidget,QAction,QPushButton,QApplication,QListWidget,QGridLayout,QLabel,QDesktopWidget,QTextEdit,QTabWidget,QVBoxLayout,QFormLayout,QLineEdit,QMessageBox,QPlainTextEdit
    from PySide2.QtCore import QTimer,QDateTime,Qt
    from PySide2.QtSql import QSqlDatabase, QSqlTableModel, QSqlQuery
else:
    # if running on your Raspberry Pi, these imports, and actions, might be what you need
    from PyQt5.QtWidgets import QMainWindow,QWidget,QAction,QPushButton,QApplication,QListWidget,QGridLayout,QLabel,QDesktopWidget,QTextEdit,QTabWidget,QVBoxLayout,QFormLayout,QLineEdit,QMessageBox,QPlainTextEdit
    from PyQt5.QtCore import QTimer,QDateTime,Qt
    from PyQt5.QtSql import QSqlDatabase, QSqlTableModel, QSqlQuery
    import serial
    ser = serial.Serial(serial_port, 9600, timeout = 2)
    import pigpio
    pi = pigpio.pi()
    pi.set_mode(screen_lock_rpi_pin, pigpio.INPUT)
    pi.set_pull_up_down(screen_lock_rpi_pin, pigpio.PUD_UP)

# imports
import sys
import time
import os
import re

# setup database
db = QSqlDatabase("QSQLITE")
db.setDatabaseName("test.sqlite")
db.open()
db.exec_("CREATE TABLE IF NOT EXISTS contact (name STRING, mobile NUMBER);")
db.exec_("CREATE TABLE IF NOT EXISTS sms (mobile NUMBER, message STRING, received_at DATETIME);")


class WinForm(QWidget):
    def __init__(self,parent=None):

        super(WinForm, self).__init__(parent)
        self.setWindowTitle('Phone')
        self.resize(400, 600)
        qr = self.frameGeometry()
        cp = QDesktopWidget().availableGeometry().center()
        qr.moveCenter(cp)
        self.move(qr.topLeft())
        layout=QVBoxLayout()

        # global variables
        self.dialling = ""
        self.gps_active = False
        self.counter = 0
        self.network = ""
        self.signal = ""
        self.call_state = ""

        # initialize tab screen
        self.tabs = QTabWidget()
        self.tab1 = QWidget()
        self.tab2 = QWidget()
        self.tab3 = QWidget()
        self.tab4 = QWidget()
        #self.tabs.resize(300, 500)

        # add tabs
        self.tabs.addTab(self.tab1, "Call")
        self.tabs.addTab(self.tab2, "SMS")
        self.tabs.addTab(self.tab3, "Contacts")
        self.tabs.addTab(self.tab4, "Cmd")

        # create tab #1 - Calling
        self.tab1.layout = QGridLayout(self)
        self.tab1.label = QLabel('Starting...')
        self.tab1.label.setAlignment(Qt.AlignCenter);
        self.tab1.btnGreenPhone = QPushButton('Answer')
        self.tab1.btnRedPhone = QPushButton('Hang up')
        self.tab1.btnDial1 = QPushButton('1')
        self.tab1.btnDial2 = QPushButton('2')
        self.tab1.btnDial3 = QPushButton('3')
        self.tab1.btnDial4 = QPushButton('4')
        self.tab1.btnDial5 = QPushButton('5')
        self.tab1.btnDial6 = QPushButton('6')
        self.tab1.btnDial7 = QPushButton('7')
        self.tab1.btnDial8 = QPushButton('8')
        self.tab1.btnDial9 = QPushButton('9')
        self.tab1.btnDial0 = QPushButton('0')
        self.tab1.layout.addWidget(self.tab1.label,0,0,1,3)
        self.tab1.layout.addWidget(self.tab1.btnGreenPhone,1,0)
        self.tab1.layout.addWidget(self.tab1.btnRedPhone,1,2)
        self.tab1.layout.addWidget(self.tab1.btnDial1,2,0)
        self.tab1.layout.addWidget(self.tab1.btnDial2,2,1)
        self.tab1.layout.addWidget(self.tab1.btnDial3,2,2)
        self.tab1.layout.addWidget(self.tab1.btnDial4,3,0)
        self.tab1.layout.addWidget(self.tab1.btnDial5,3,1)
        self.tab1.layout.addWidget(self.tab1.btnDial6,3,2)
        self.tab1.layout.addWidget(self.tab1.btnDial7,4,0)
        self.tab1.layout.addWidget(self.tab1.btnDial8,4,1)
        self.tab1.layout.addWidget(self.tab1.btnDial9,4,2)
        self.tab1.layout.addWidget(self.tab1.btnDial0,5,1)
        self.tab1.setLayout(self.tab1.layout)
        self.tab1.btnDial0.clicked.connect(lambda: self.dialNumber("0"))
        self.tab1.btnDial1.clicked.connect(lambda: self.dialNumber("1"))
        self.tab1.btnDial2.clicked.connect(lambda: self.dialNumber("2"))
        self.tab1.btnDial3.clicked.connect(lambda: self.dialNumber("3"))
        self.tab1.btnDial4.clicked.connect(lambda: self.dialNumber("4"))
        self.tab1.btnDial5.clicked.connect(lambda: self.dialNumber("5"))
        self.tab1.btnDial6.clicked.connect(lambda: self.dialNumber("6"))
        self.tab1.btnDial7.clicked.connect(lambda: self.dialNumber("7"))
        self.tab1.btnDial8.clicked.connect(lambda: self.dialNumber("8"))
        self.tab1.btnDial9.clicked.connect(lambda: self.dialNumber("9"))
        self.tab1.btnGreenPhone.clicked.connect(self.greenPhone)
        self.tab1.btnRedPhone.clicked.connect(self.redPhone)
        self.tab1.btnGreenPhone.setEnabled(False)
        self.tab1.btnRedPhone.setEnabled(False)

        # create tab #2 - SMS
        self.tab2.layout = QGridLayout(self)
        self.tab2.smsMobile = QLineEdit()
        self.tab2.smsText = QPlainTextEdit()
        self.tab2.layout.addWidget(QLabel("Mobile:"),0,0,1,1)
        self.tab2.layout.addWidget(self.tab2.smsMobile,0,1,1,3)
        self.tab2.layout.addWidget(self.tab2.smsText,1,0,2,4)
        self.tab2.btnCall = QPushButton('Call')
        self.tab2.btnReply = QPushButton('Reply')
        self.tab2.btnDelete = QPushButton('Del')
        self.tab2.btnSend = QPushButton('Send')
        self.tab2.layout.addWidget(self.tab2.btnCall,3,0)
        self.tab2.layout.addWidget(self.tab2.btnReply,3,1)
        self.tab2.layout.addWidget(self.tab2.btnDelete,3,2)
        self.tab2.layout.addWidget(self.tab2.btnSend,3,3)
        self.tab2.listwidget = QListWidget()
        self.tab2.listwidget.setWordWrap(True)
        self.tab2.listwidget.setStyleSheet("QListWidget::item { border-bottom: 1px solid grey; padding: 10 0; } QListWidget::item:selected { color: black; background: rgb(210,210,210); }")
        self.listSMSs()
        self.tab2.listwidget.clicked.connect(self.selectSMS)
        self.tab2.layout.addWidget(self.tab2.listwidget,4,0,4,4)
        self.tab2.btnCall.setEnabled(False)
        self.tab2.btnReply.setEnabled(False)
        self.tab2.btnDelete.setEnabled(False)
        self.tab2.setLayout(self.tab2.layout)
        self.tab2.btnCall.clicked.connect(self.callSelectedContact)
        self.tab2.btnReply.clicked.connect(self.smsSelectedContact)
        self.tab2.btnDelete.clicked.connect(self.deleteSMS)
        self.tab2.btnSend.clicked.connect(self.sendSMS)

        # create tab #3 - People / address book / contacts
        self.tab3.layout = QGridLayout(self)
        self.tab3.newContactName = QLineEdit()
        self.tab3.newContactMobile = QLineEdit()
        self.tab3.layout.addWidget(QLabel("Name:"),0,0,1,1)
        self.tab3.layout.addWidget(self.tab3.newContactName,0,1,1,3)
        self.tab3.layout.addWidget(QLabel("Mobile:"),1,0,1,1)
        self.tab3.layout.addWidget(self.tab3.newContactMobile,1,1,1,3)
        self.tab3.btnCall = QPushButton('Call')
        self.tab3.btnSMS = QPushButton('SMS')
        self.tab3.btnDelete = QPushButton('Del')
        self.tab3.btnSave = QPushButton('Save')
        self.tab3.layout.addWidget(self.tab3.btnCall,2,0)
        self.tab3.layout.addWidget(self.tab3.btnSMS,2,1)
        self.tab3.layout.addWidget(self.tab3.btnDelete,2,2)
        self.tab3.layout.addWidget(self.tab3.btnSave,2,3)
        self.tab3.listwidget = QListWidget()
        self.tab3.listwidget.setStyleSheet("QListWidget::item { border-bottom: 1px solid grey; padding: 10 0; } QListWidget::item:selected { color: black; background: rgb(210,210,210); }")
        self.listContacts()
        self.tab3.listwidget.clicked.connect(self.selectContact)
        self.tab3.layout.addWidget(self.tab3.listwidget,3,0,1,4)
        self.tab3.btnCall.setEnabled(False)
        self.tab3.btnSMS.setEnabled(False)
        self.tab3.btnDelete.setEnabled(False)
        self.tab3.setLayout(self.tab3.layout)
        self.tab3.btnCall.clicked.connect(self.callSelectedContact)
        self.tab3.btnSMS.clicked.connect(self.smsSelectedContact)
        self.tab3.btnDelete.clicked.connect(self.deleteContact)
        self.tab3.btnSave.clicked.connect(self.saveNewContact)

        # create tab #4 - Commands / debug / console
        self.tab4.layout = QGridLayout(self)
        self.tab4.log = QTextEdit()
        self.tab4.btnPhoto = QPushButton('Photo')
        self.tab4.btnGPSOn = QPushButton('GPS On')
        self.tab4.btnGPSOff = QPushButton('GPS Off')
        self.tab4.btnNetwork = QPushButton('Network')
        self.tab4.btnSignal = QPushButton('Signal')
        self.tab4.layout.addWidget(self.tab4.log,0,0,1,3)
        self.tab4.layout.addWidget(self.tab4.btnPhoto,2,0)
        self.tab4.layout.addWidget(self.tab4.btnGPSOn,2,1)
        self.tab4.layout.addWidget(self.tab4.btnGPSOff,2,2)
        self.tab4.layout.addWidget(self.tab4.btnNetwork,3,0)
        self.tab4.layout.addWidget(self.tab4.btnSignal,3,1)
        self.tab4.setLayout(self.tab4.layout)
        self.tab4.btnPhoto.clicked.connect(lambda: self.takePhoto())
        self.tab4.btnGPSOn.clicked.connect(lambda: self.toggleGPS(True))
        self.tab4.btnGPSOff.clicked.connect(lambda: self.toggleGPS(False))
        self.tab4.btnNetwork.clicked.connect(lambda: self.writeToSerial("AT+COPS?"))
        self.tab4.btnSignal.clicked.connect(lambda: self.writeToSerial("AT+CSQ"))

        # add tabs to widget
        layout.addWidget(self.tabs)
        self.setLayout(layout)

        # start the timer thread
        self.timer = QTimer()
        self.timer.timeout.connect(self.refreshScreen)
        self.timer.start(1000)


    def refreshScreen(self):

        # increment the counter
        self.counter = self.counter + 1
        if (self.counter == 1000):
            self.counter = 0

        # get the network name
        if (self.counter == 1):
            self.writeToSerial("AT+COPS?")

        # get the network signal strength, every 50 seconds
        if (self.counter % 50 == 5):
            self.writeToSerial("AT+CSQ")

        # get GPS position, every 25 seconds
        if (self.gps_active):
            if (self.counter % 25 == 0):
                self.writeToSerial("AT+CGPSINFO")

        # scan for new SMS messages, every 100 seconds
        if (self.counter % 100 == 20):
            self.downloadSMSs()

        # play ringtone if incoming call, every 2 seconds
        if (self.call_state == "incoming"):
            if (self.counter % 2 == 0):
                os.system("aplay ringtone.wav > /dev/null 2>&1")

        # update the screen
        if (self.call_state == ""):
            if (self.dialling == ""):
                thetime = QDateTime.currentDateTime()
                time_display = thetime.toString('hh:mm:ss')
                if (self.network != "" and self.signal != ""):
                    time_display = self.network + " " + str(int(int(self.signal)/31*100)) + "%\n" + time_display
                self.tab1.label.setText(time_display)
            else:
                self.tab1.label.setText("Dial "+self.dialling)
                self.tab1.btnRedPhone.setEnabled(True)
                self.tab1.btnRedPhone.setText("Cancel")
                self.tab1.btnGreenPhone.setText("Call")
                if (len(self.dialling) > 10):
                    self.tab1.btnGreenPhone.setEnabled(True)
        else:
            if (self.call_state == "incoming"):
                self.tab1.label.setText("Incoming call!")
                self.tab1.btnRedPhone.setEnabled(True)
                self.tab1.btnGreenPhone.setEnabled(True)
                self.tab1.btnRedPhone.setText("Reject")
                self.tab1.btnGreenPhone.setText("Answer")
            if (self.call_state == "outgoing"):
                self.tab1.label.setText("Making call...")
                self.tab1.btnGreenPhone.setEnabled(False)
                self.tab1.btnRedPhone.setEnabled(True)
                self.tab1.btnRedPhone.setText("Hang up")
            if (self.call_state == "busy"):
                self.tab1.label.setText("On phone call")
                self.tab1.btnGreenPhone.setEnabled(False)
                self.tab1.btnRedPhone.setEnabled(True)
                self.tab1.btnGreenPhone.setText("Answer")
                self.tab1.btnRedPhone.setText("Hang up")


        # read from serial port
        read_str = self.readFromSerial()


        # take action on responses
        if "CGPSINFO" in read_str:
            bits = read_str.split("CGPSINFO: ")
            f = open("location.txt", "w")
            f.write(bits[1])
            f.close

        if "COPS:" in read_str:
            bits = read_str.split(",")
            self.network = bits[2].strip('\"')

        if "CSQ:" in read_str:
            bits = read_str.split("CSQ: ")
            temp = bits[1].split(",")
            self.signal = temp[0]

        if "RING" in read_str:
            self.call_state = "incoming"

        if "MISSED_CALL" in read_str:
            self.call_state = ""
            self.hearPhoneAudio(False)

        if "BUSY" in read_str:
            self.call_state = ""
            self.hearPhoneAudio(False)

        if "NO CARRIER" in read_str:
            self.call_state = ""
            self.hearPhoneAudio(False)

        if "VOICE CALL: BEGIN" in read_str:
            self.call_state = "busy"
            self.writeToSerial("AT+CMICGAIN=5")
            self.hearPhoneAudio(True)

        if "VOICE CALL: END" in read_str:
            self.call_state = ""
            self.hearPhoneAudio(False)

        if "+CMTI:" in read_str:
            self.downloadSMSs()
            self.alert("New SMS received!")


        # turn on / off screen lock
        if (not testing):
            screen_lock = pi.read(screen_lock_rpi_pin)
            if (screen_lock == 1):
                os.system("xset dpms force on")
                os.system("xinput enable 6")
            else:
                os.system("xset dpms force off")
                os.system("xinput disable 6")


    def writeToSerial(self,cmd):
        self.tab4.log.append("> "+cmd)
        if (not testing):
            cmd = cmd + "\r"
            ser.close()
            ser.open()
            ser.write(cmd.encode())
        else:
            print("> "+cmd)


    def readFromSerial(self, buffer = 64):
        if (not testing):
            read_val = ser.read(size=buffer)
            read_str = bytearray(read_val).decode()
            if (len(read_str) > 1):
                temp = read_str.strip()
                temp = temp.replace("\r\n\r\n", "\n")
                temp = temp.replace("\r\r\n", "\n")
                self.tab4.log.append(temp)
            return read_str
        else:
            return "-"


    def downloadSMSs(self):
        self.writeToSerial('AT+CMGL="ALL"')
        message_dump = self.readFromSerial(5000)
        messages = message_dump.split("+CMGL:")
        count = 0
        for message in messages:
            lines = message.split("\r\n")
            if (len(lines) > 1):
                message = lines[1]
                temp = lines[0].split(",")
                if (len(temp) > 5):
                    mobile = temp[2].strip('\"')
                    if (len(mobile) > 20):
                        mobile = bytes.fromhex(mobile).decode('ascii').replace(chr(0),"")
                        message = bytes.fromhex(message).decode('ascii').replace(chr(0),"")
                    if (mobile[0] == "+"):
                        mobile = mobile[1:]
                    date = temp[4].strip('\"')
                    time = temp[5].strip('\"')
                    date = "20" + date
                    date = date.replace('/', "-")
                    temp = time.split("+")
                    time = temp[0]
                    timestamp = date + " " + time
                    query = QSqlQuery(db)
                    query.prepare("INSERT INTO sms (mobile,message,received_at) VALUES (:mobile,:message,:received_at)")
                    query.bindValue(":mobile", mobile)
                    query.bindValue(":message", message)
                    query.bindValue(":received_at", timestamp)
                    query.exec()
                    count = count + 1
        if (count > 0):
            self.writeToSerial("AT+CMGD=,4")
            self.listSMSs()


    def listSMSs(self):
        query = QSqlQuery(db)
        query.exec_("SELECT mobile,name FROM contact")
        saved_contacts = {}
        while query.next():
            saved_contacts[query.value(0)] = query.value(1)
        query = QSqlQuery(db)
        query.exec_("SELECT mobile,message,received_at FROM sms ORDER BY received_at DESC")
        row = 0
        self.tab2.listwidget.clear()
        while query.next():
            person = '+' + str(query.value(0))
            if (query.value(0) in saved_contacts):
                person = person + '\n' + saved_contacts[query.value(0)]
            self.tab2.listwidget.insertItem(row, str(query.value(2)) + ': ' + person + '\n' + str(query.value(1)))
            row = row + 1


    def listContacts(self):
        query = QSqlQuery(db)
        query.exec_("SELECT name,mobile FROM contact ORDER BY name DESC")
        row = 0
        self.tab3.listwidget.clear()
        while query.next():
            self.tab3.listwidget.insertItem(row, query.value(0) + ' +' + str(query.value(1)))
            row = row + 1


    def selectSMS(self, qmodelindex):
        sms = self.tab2.listwidget.currentItem().text()
        temp = sms.split(": +")
        self.current_sms_timestamp = temp[0]
        temp = temp[1].split('\n')
        self.current_contact_number = temp[0]
        self.tab2.btnCall.setEnabled(True)
        self.tab2.btnReply.setEnabled(True)
        self.tab2.btnDelete.setEnabled(True)


    def selectContact(self, qmodelindex):
        contact = self.tab3.listwidget.currentItem().text()
        temp = contact.split("+")
        self.current_contact_number = temp[1]
        self.tab3.btnCall.setEnabled(True)
        self.tab3.btnSMS.setEnabled(True)
        self.tab3.btnDelete.setEnabled(True)


    def callSelectedContact(self):
        self.dialling = self.current_contact_number
        self.tabs.setCurrentIndex(0)


    def smsSelectedContact(self):
        self.tab2.smsMobile.setText(self.current_contact_number)
        self.tab2.smsText.setFocus()
        self.tabs.setCurrentIndex(1)


    def deleteContact(self):
        query = QSqlQuery(db)
        query.exec_("DELETE FROM contact WHERE mobile LIKE \""+self.current_contact_number+"\"")
        self.listContacts()


    def deleteSMS(self):
        query = QSqlQuery(db)
        query.exec_("DELETE FROM sms WHERE received_at LIKE \""+self.current_sms_timestamp+"\"")
        self.listSMSs()


    def saveNewContact(self):
        name = self.tab3.newContactName.text().title()
        nameClean = re.sub(r'[^A-Za-z ]', '', name)
        mobile = self.tab3.newContactMobile.text()
        mobileClean = re.sub(r'[^0-9]', '', mobile)
        if (len(nameClean) < 1):
            self.alert("Name to short")
        else:
            if (len(mobileClean) < 11):
                self.alert("Number to short")
            else:
                query = QSqlQuery(db)
                query.exec_("INSERT INTO contact (name,mobile) VALUES (\""+nameClean+"\",\""+mobileClean+"\")")
                self.listContacts()
                self.tab3.newContactName.setText("")
                self.tab3.newContactMobile.setText("")
                self.alert("Contact saved")


    def dialNumber(self,num):
        self.dialling = self.dialling + num;
        self.refreshScreen;


    def greenPhone(self):
        if (self.call_state == "incoming"):
            self.writeToSerial("ATA")
        if (len(self.dialling) > 10):
            self.tab1.label.setText("Dialling "+self.dialling+"...")
            self.writeToSerial("ATD+"+self.dialling+";")
            self.hearPhoneAudio(True)
            self.call_state = "outgoing"


    def redPhone(self):
        self.dialling = ""
        self.call_state = ""
        self.tab1.btnGreenPhone.setEnabled(False)
        self.tab1.btnRedPhone.setEnabled(False)
        self.tab1.btnRedPhone.setText("Hang up")
        self.tab1.btnGreenPhone.setText("Answer")
        self.writeToSerial("AT+CHUP")


    def hearPhoneAudio(self,on):
        if (not testing):
            if (on):
                pi.write(audio_changeover_rpi_pin,1)
            else:
                pi.write(audio_changeover_rpi_pin,0)


    def takePhoto(self):
        thetime = QDateTime.currentDateTime()
        time_stamp = thetime.toString('yyyyMMdd-hhmmss')
        os.system("libcamera-still -o photo-"+time_stamp+".jpg --qt-preview")


    def toggleGPS(self,on):
        if (on):
            self.writeToSerial("AT+CGPS=1")
            self.gps_active = True
        else:
            self.writeToSerial("AT+CGPS=0")
            self.gps_active = False
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

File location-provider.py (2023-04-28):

from flask import Flask
#from signal import pause

app = Flask(__name__)


@app.route("/", methods=['GET', 'POST'])
def hello_world():
    f = open("location.txt", "r")
    location = f.read()
    f.close
    bits = location.split(",")
    
    # latitude first
    temp = bits[0].lstrip("0")
    numbers = float(bits[0])/100
    strnumbers = str(numbers)
    temp = strnumbers.split(".")
    value1 = int(temp[0])
    temp = numbers - value1
    lat = int(value1) + (temp*100)/60
    if (bits[1] == "S"):
        lat = lat * -1
        
    # longitude first
    temp = bits[0].lstrip("0")
    numbers = float(bits[2])/100
    strnumbers = str(numbers)
    temp = strnumbers.split(".")
    value1 = int(temp[0])
    temp = numbers - value1
    lng = int(value1) + (temp*100)/60
    if (bits[3] == "W"):
        lng = lng * -1
    
    return("{\"location\": {\"lat\": "+str(lat) +", \"lng\": "+str(lng)+"}, \"accuracy\": "+bits[5]+"}")
    #return(f.read());
    #return"{\"location\": {\"lat\": -33.7, \"lng\": 18.4}, \"accuracy\": 25000}"

#pause()
if __name__ == "__main__":
    app.run(debug=True)

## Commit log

2023-06-06 Update README.md
    adding a thingiverse link to 3D print the parts
2025-04-06 Added schematic and PCB file
2025-04-22 ESD diode added, GPIO buttons switched to 3.3v, resistors on LED
2025-10-22 Latest PCB project file
